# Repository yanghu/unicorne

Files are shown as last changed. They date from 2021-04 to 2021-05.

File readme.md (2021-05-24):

# Unicorne - A single-piece 40% ortho keyboard inspired by Corne and more.

This is the keyboard design files for my own use, inspired by
[crkbd](https://github.com/foostan/crkbd),
[Kyria](https://blog.splitkb.com/blog/introducing-the-kyria) and
[Ferris](https://github.com/pierrechevalier83/ferris), as well as
[Reviung41](https://github.com/gtips/reviung) and others.

The name means "uni(single-piece)corne".

## Summary of board features

* USB-C connector
* Audio buzzer
* Rotary encoder x 2 (optional)
* Underglow RGB LEDs x8
* SMT32 MCU (STM32F411)
* OLED display
* Column stagger similar to Kyria.
* Corne-style thumb cluster with extra inner key: I feel Kyria's thumb cluster 
is too much and the outer column is hard to reach for me. 
* Thumb cluster shifted 0.25u to the middle.

## Links

* [PCB repo](unicorne-mx/unicorne).
* [PCB ibom
](https://yanghu.github.io/unicorne/artifacts/ibom/unicorn-ibom.html)
* [Fabrication files and firmware](https://github.com/yanghu/unicorne/releases/tag/v1.0)
* [QMK firmware repo](https://github.com/yanghu/qmk_firmware/tree/unicorne/keyboards/yanghu/unicorne).
* [Build guide](https://github.com/yanghu/unicorne/wiki/Build-guide)

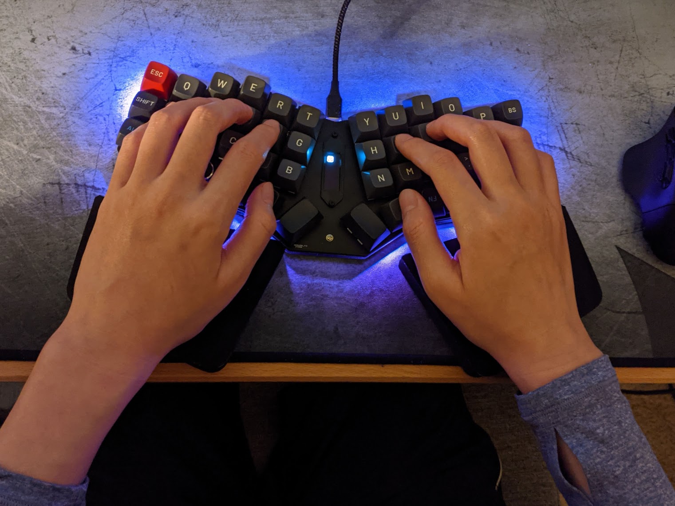
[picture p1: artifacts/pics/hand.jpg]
hand

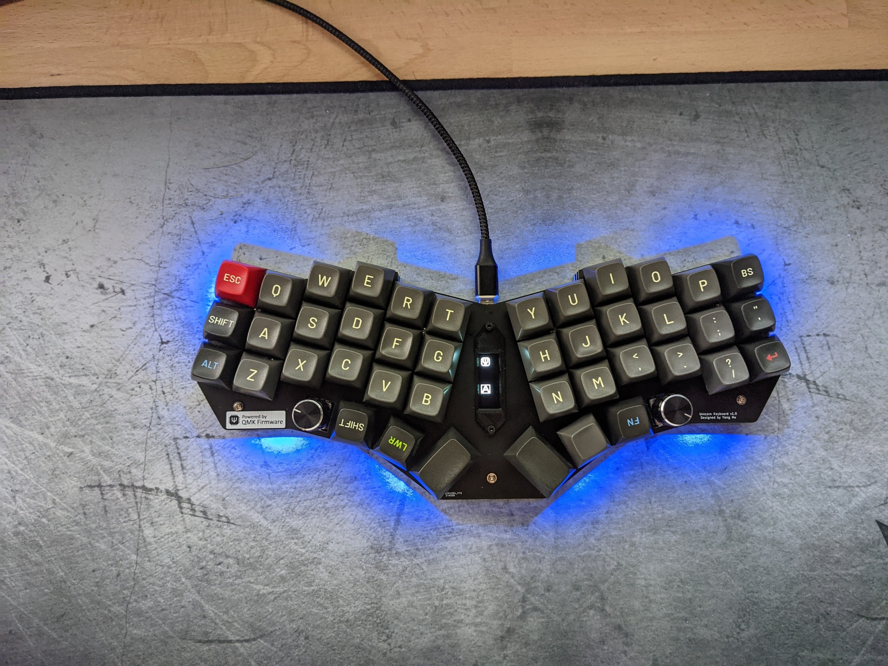
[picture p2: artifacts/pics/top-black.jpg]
keyboard

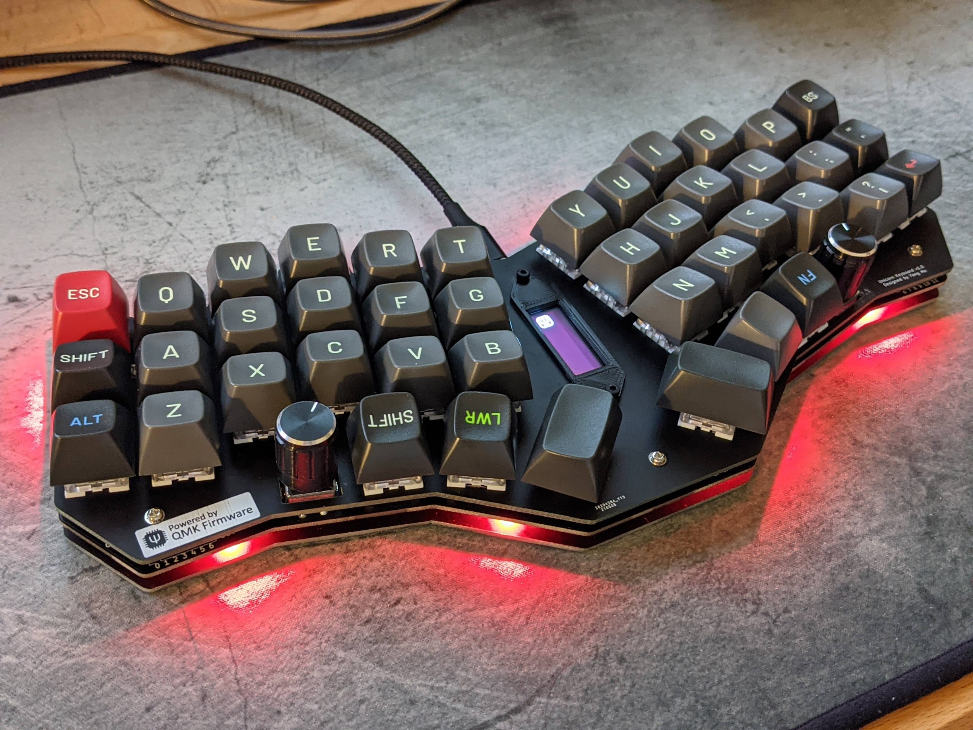
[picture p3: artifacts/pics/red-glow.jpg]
keyboard2

pcb1

## Why I designed this board

I like the simplicity of Corne, however, the more aggresive column stagger
on Kyria suits my hand better. I also removed the use of pro micro boards, and
followed Ferris 2.0 with an ARM chip directly on the board.

The initial reason I wanted to design this board is to eliminate the ugly
"add-on" board of promicro. Ferris is nice but I needed a 3x6 with full thumb
clusters as well: portability is not an issue for me.

I initially thought about building a split keyboard, however, after used crkbd
for a while, I missed the simplicity of a one-piece board: it's always symmetric
and has smaller footprint.

I do use a Planck, but *ortho* is not really a good idea on traditional keyboard
layout: the hands are so close and it's awkward to keep hands "vertical": the
wrist really is painful, especially after used to more ergonomic splits.

Reviung-like keyboards really gave me the inspiration. The angle ensures arms
and hands are in line, while you can still use the ortho layout.

Other features are nice and in different designs. I like the buzzer on Planck
that tells you when the keyboard is alive. The small OLED really is useful to
display status information for a programmable board. The encoder can be pretty
versatile.

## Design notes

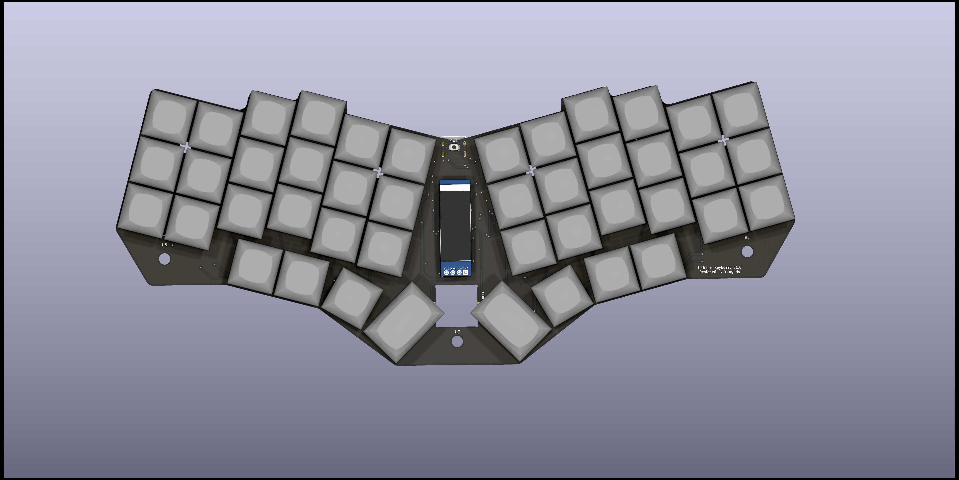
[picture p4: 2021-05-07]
artifacts/render/unicorn.png

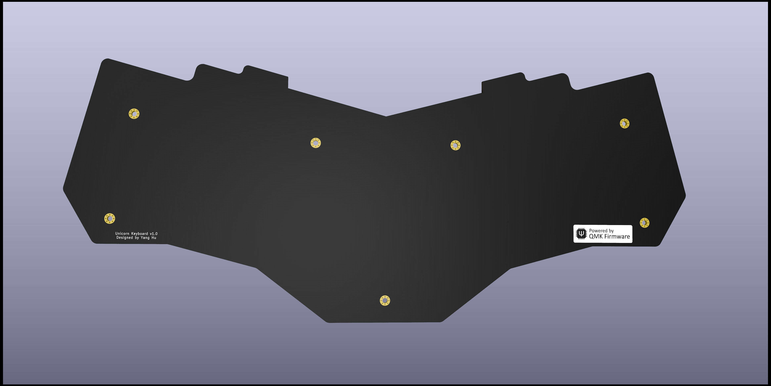
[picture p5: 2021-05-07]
artifacts/render/bottom.png

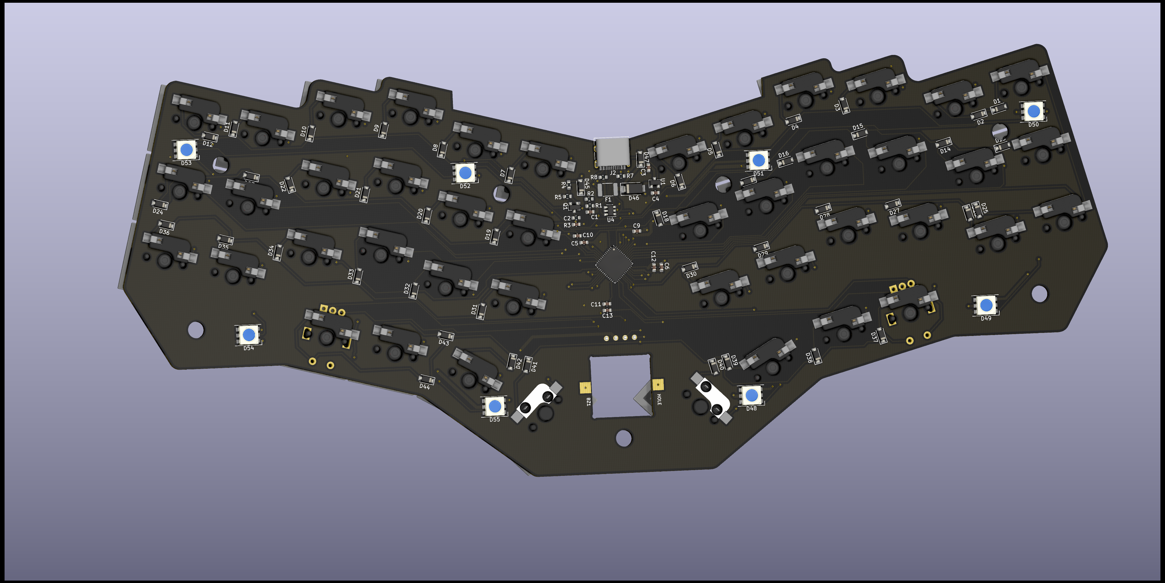
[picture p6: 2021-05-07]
artifacts/render/unicorn-back.png

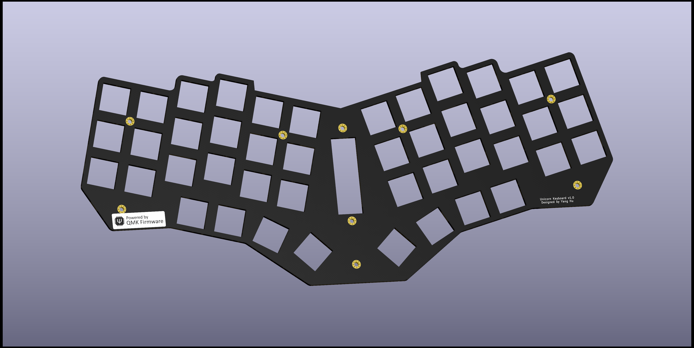
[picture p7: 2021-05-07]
artifacts/render/plate.png

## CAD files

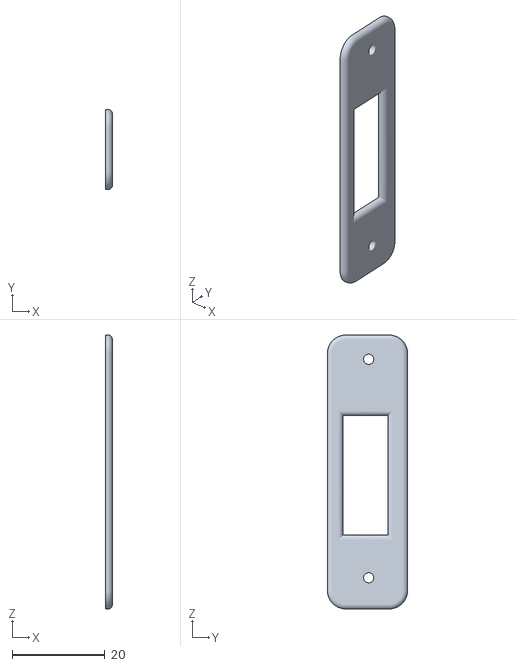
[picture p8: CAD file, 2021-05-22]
mechanical/oled-cover.stl
1.50 x 17.3 x 58.9

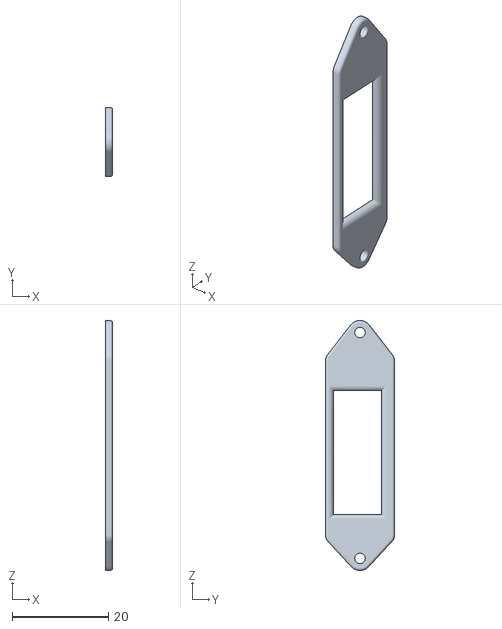
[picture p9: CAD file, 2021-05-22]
mechanical/oled-cover-v2.stl
1.50 x 14.4 x 52.0

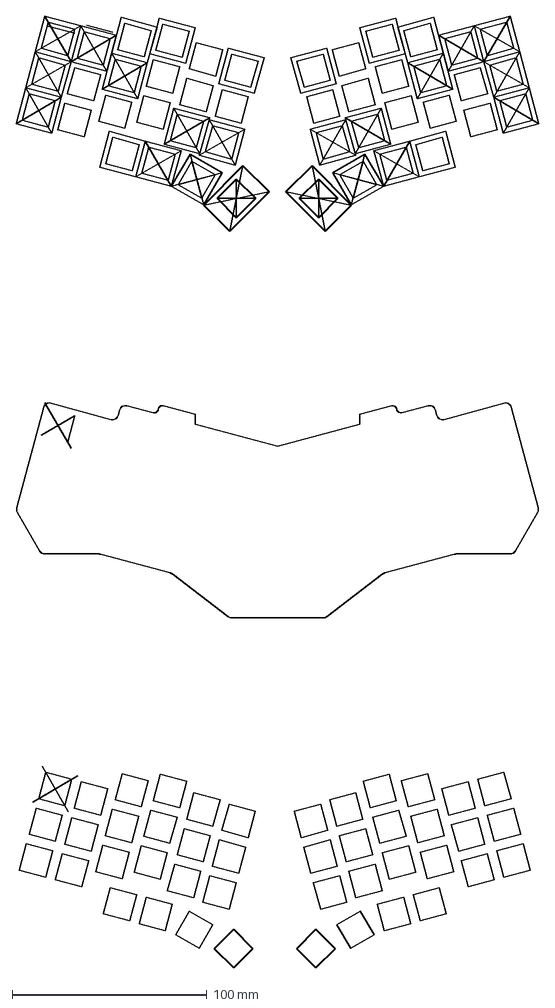
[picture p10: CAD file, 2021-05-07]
mechanical/layout.dxf
268.6 x 489.0 mm

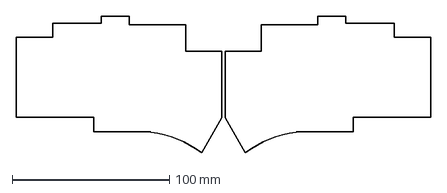
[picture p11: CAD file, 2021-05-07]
mechanical/outline.dxf
264.0 x 87.1 mm

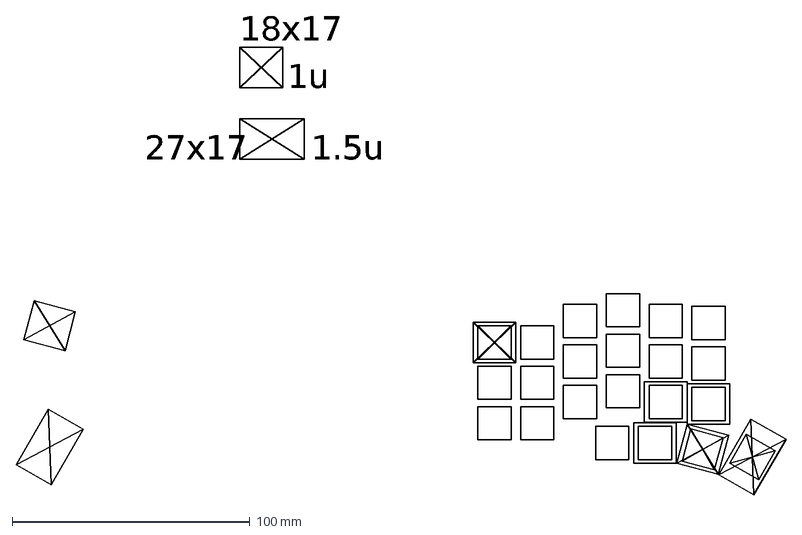
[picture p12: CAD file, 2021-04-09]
mechanical/choc-layout.dxf
1u
18x17
1.5u
27x17

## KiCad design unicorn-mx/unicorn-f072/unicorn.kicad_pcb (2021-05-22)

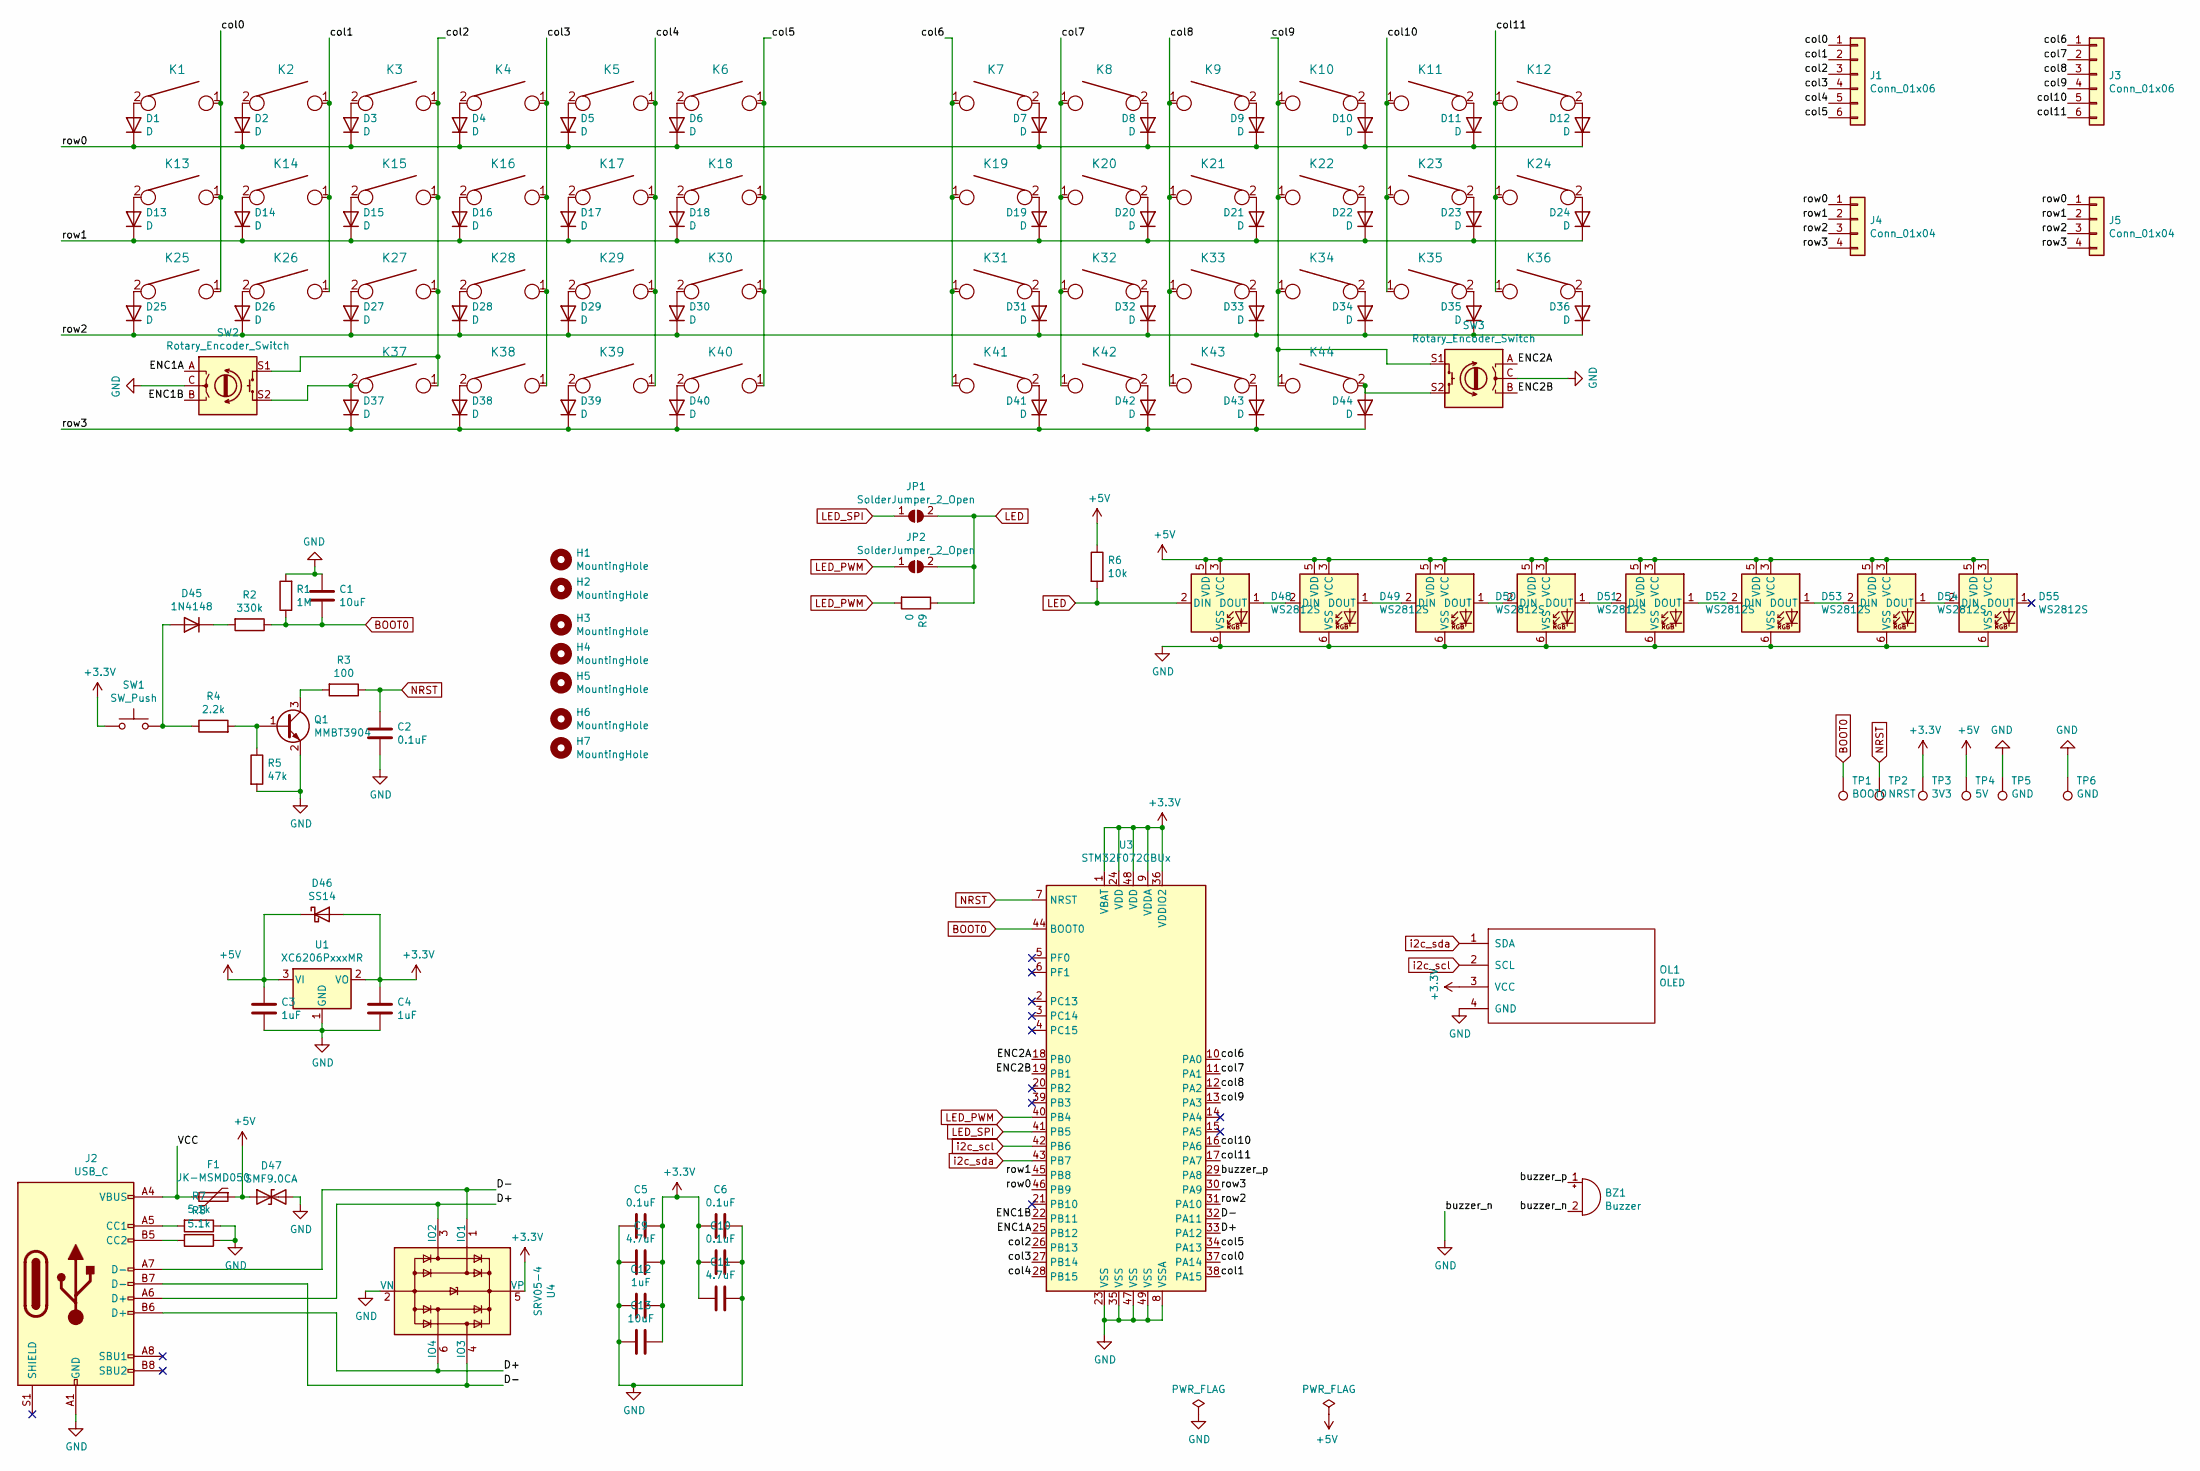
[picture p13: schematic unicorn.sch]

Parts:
BZ1: Buzzer; Piezo-KLJ-1625; LCSC Part C201041
C1, C13: 10uF; C_0603_1608Metric; LCSC Part C19702
C2, C5, C6, C10: 0.1uF; C_0603_1608Metric; LCSC Part C14663
C3, C4, C12: 1uF; C_0603_1608Metric; LCSC Part C15849
C9, C11: 4.7uF; C_0603_1608Metric; LCSC Part C19666
D1, D2, D3, D4, D5, D6, D7, D8, D9, D10, D11, D12, D13, D14, D15, D16, D17, D18, D19, D20, D21, D22, D23, D24, D25, D26, D27, D28, D29, D30, D31, D32, D33, D34, D35, D36, D37, D38, D39, D40, D41, D42, D43, D44: D; D_SOD-123; LCSC Part C81598
D45: 1N4148; D_SOD-123; LCSC Part C81598
D46: SS14; D_SMA; LCSC Part C2480
D47: SMF9.0CA; D_SOD-123; LCSC Part C435473
D48, D49, D50, D51, D52, D53, D54, D55: WS2812S; LED_WS2812_PLCC6_5.0x5.0mm_P1.6mm; LCSC Part C114584
F1: JK-MSMD050; Fuse_1812_4532Metric; LCSC Part C369167
H1, H2, H3, H4, H5, H6, H7: MountingHole; MountingHole_4.5mm
J1, J3: Conn_01x06; PinHeader_1x06_P2.54mm_Vertical
J2: USB_C; USB_C_HRO_TYPE-C-31-M-12; LCSC Part C165948
J4, J5: Conn_01x04; PinHeader_1x04_P2.54mm_Vertical
JP1, JP2: SolderJumper_2_Open; SolderJumper-2_P1.3mm_Open_TrianglePad1.0x1.5mm
K1, K2, K3, K4, K5, K6, K7, K8, K9, K10, K11, K12, K13, K14, K15, K16, K17, K18, K19, K20, K21, K22, K23, K24, K25, K26, K27, K28, K29, K30, K31, K32, K33, K34, K35, K36, K37, K38, K39, K42, K43, K44: KEYSW; CherryMX_Hotswap
K40, K41: KEYSW; CherryMX_Hotswap_1.5u
OL1: OLED; OLED_v2
Q1: MMBT3904; SOT-23; LCSC Part C20526
R1: 1M; R_0603_1608Metric; LCSC Part C22935
R2: 330k; R_0603_1608Metric; LCSC Part C23137
R3: 100; R_0603_1608Metric; LCSC Part C22775
R4: 2.2k; R_0603_1608Metric; LCSC Part C4190
R5: 47k; R_0603_1608Metric; LCSC Part C25819
R6: 10k; R_0603_1608Metric; LCSC Part C25804
R7, R8: 5.1k; R_0603_1608Metric; LCSC Part C23186
R9: 0; R_0603_1608Metric; LCSC Part C21189
SW1: SW_Push; SW_SPST_B3U-1000P; LCSC Part C231329
SW2, SW3: Rotary_Encoder_Switch; RotaryEncoder_EC11
TP1: BOOT0; TestPoint_THTPad_D1.5mm_Drill0.7mm
TP2: NRST; TestPoint_THTPad_D1.5mm_Drill0.7mm
TP3: 3V3; TestPoint_THTPad_D1.5mm_Drill0.7mm
TP4: 5V; TestPoint_THTPad_D1.5mm_Drill0.7mm
TP5, TP6: GND; TestPoint_THTPad_D1.5mm_Drill0.7mm
U1: XC6206PxxxMR; SOT-23; LCSC Part C5446
U3: STM32F072CBUx; QFN-48-1EP_7x7mm_P0.5mm_EP5.15x5.15mm_ThermalVias; LCSC Part C92504
U4: SRV05-4; SOT-23-6; LCSC Part C85364

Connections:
+3V3: C4.2, C5.1, C6.2, C9.1, C10.2, C11.2, C12.1, C13.1, D46.2 (A), OL1.3 (VCC), SW1.1, TP3.1, U1.2 (VO), U3.1 (VBAT), U3.9 (VDDA), U3.24 (VDD), U3.36 (VDDIO2), U3.48 (VDD), U4.5 (VP)
+5V: C3.2, D46.1 (K), D47.1 (A1), D48.3 (VCC), D48.5 (VDD), D49.3 (VCC), D49.5 (VDD), D50.3 (VCC), D50.5 (VDD), D51.3 (VCC), D51.5 (VDD), D52.3 (VCC), D52.5 (VDD), D53.3 (VCC), D53.5 (VDD), D54.3 (VCC), D54.5 (VDD), D55.3 (VCC), D55.5 (VDD), F1.1, R6.1, TP4.1, U1.3 (VI)
/D+: J2.A6 (D+), J2.B6 (D+), U3.33 (PA12), U4.3 (IO2), U4.6 (IO4)
/D-: J2.A7 (D-), J2.B7 (D-), U3.32 (PA11), U4.1 (IO1), U4.4 (IO3)
/ENC1A: SW2.A, U3.25 (PB12)
/ENC1B: SW2.B, U3.22 (PB11)
/ENC2A: SW3.A, U3.18 (PB0)
/ENC2B: SW3.B, U3.19 (PB1)
/VCC: F1.2, J2.A4 (VBUS), J2.A9 (VBUS), J2.B4 (VBUS), J2.B9 (VBUS)
/buzzer_p: BZ1.1 (-), U3.29 (PA8)
/col0: J1.1, K1.1, K13.1, K25.1, U3.37 (PA14)
/col1: J1.2, K2.1, K14.1, K26.1, U3.38 (PA15)
/col2: J1.3, K3.1, K15.1, K27.1, K37.1, SW2.S1, U3.26 (PB13)
/col3: J1.4, K4.1, K16.1, K28.1, K38.1, U3.27 (PB14)
/col4: J1.5, K5.1, K17.1, K29.1, K39.1, U3.28 (PB15)
/col5: J1.6, K6.1, K18.1, K30.1, K40.1, U3.34 (PA13)
/col6: J3.1, K7.1, K19.1, K31.1, K41.1, U3.10 (PA0)
/col7: J3.2, K8.1, K20.1, K32.1, K42.1, U3.11 (PA1)
/col8: J3.3, K9.1, K21.1, K33.1, K43.1, U3.12 (PA2)
/col9: J3.4, K10.1, K22.1, K34.1, K44.1, SW3.S1, U3.13 (PA3)
/col10: J3.5, K11.1, K23.1, K35.1, U3.16 (PA6)
/col11: J3.6, K12.1, K24.1, K36.1, U3.17 (PA7)
/row0: D1.1 (K), D2.1 (K), D3.1 (K), D4.1 (K), D5.1 (K), D6.1 (K), D7.1 (K), D8.1 (K), D9.1 (K), D10.1 (K), D11.1 (K), D12.1 (K), J4.1, J5.1, U3.46 (PB9)
/row1: D13.1 (K), D14.1 (K), D15.1 (K), D16.1 (K), D17.1 (K), D18.1 (K), D19.1 (K), D20.1 (K), D21.1 (K), D22.1 (K), D23.1 (K), D24.1 (K), J4.2, J5.2, U3.45 (PB8)
/row2: D25.1 (K), D26.1 (K), D27.1 (K), D28.1 (K), D29.1 (K), D30.1 (K), D31.1 (K), D32.1 (K), D33.1 (K), D34.1 (K), D35.1 (K), D36.1 (K), J4.3, J5.3, U3.31 (PA10)
/row3: D37.1 (K), D38.1 (K), D39.1 (K), D40.1 (K), D41.1 (K), D42.1 (K), D43.1 (K), D44.1 (K), J4.4, J5.4, U3.30 (PA9)
BOOT0: C1.1, R1.1, R2.1, TP1.1, U3.44 (BOOT0)
GND: BZ1.2 (+), C1.2, C2.1, C3.1, C4.1, C5.2, C6.1, C9.2, C10.1, C11.1, C12.2, C13.2, D47.2 (A2), D48.6 (VSS), D49.6 (VSS), D50.6 (VSS), D51.6 (VSS), D52.6 (VSS), D53.6 (VSS), D54.6 (VSS), D55.6 (VSS), J2.A1 (GND), J2.A12 (GND), J2.B1 (GND), J2.B12 (GND), OL1.4 (GND), Q1.2 (E), R1.2, R5.2, R7.1, R8.1, SW2.C, SW3.C, TP5.1, TP6.1, U1.1 (GND), U3.8 (VSSA), U3.23 (VSS), U3.35 (VSS), U3.47 (VSS), U3.49 (VSS), U4.2 (VN)
LED: D48.2 (DIN), JP1.2 (B), JP2.2 (B), R6.2, R9.1
LED_PWM: JP2.1 (A), R9.2, U3.40 (PB4)
LED_SPI: JP1.1 (A), U3.41 (PB5)
NRST: C2.2, R3.1, TP2.1, U3.7 (NRST)
unnamed: D1.2 (A), K1.2
unnamed: D2.2 (A), K2.2
unnamed: D3.2 (A), K3.2
unnamed: D4.2 (A), K4.2
unnamed: D5.2 (A), K5.2
unnamed: D6.2 (A), K6.2
unnamed: D7.2 (A), K7.2
unnamed: D8.2 (A), K8.2
unnamed: D9.2 (A), K9.2
unnamed: D10.2 (A), K10.2
unnamed: D11.2 (A), K11.2
unnamed: D12.2 (A), K12.2
unnamed: D13.2 (A), K13.2
unnamed: D14.2 (A), K14.2
unnamed: D15.2 (A), K15.2
unnamed: D16.2 (A), K16.2
unnamed: D17.2 (A), K17.2
unnamed: D18.2 (A), K18.2
unnamed: D19.2 (A), K19.2
unnamed: D20.2 (A), K20.2
unnamed: D21.2 (A), K21.2
unnamed: D22.2 (A), K22.2
unnamed: D23.2 (A), K23.2
unnamed: D24.2 (A), K24.2
unnamed: D25.2 (A), K25.2
unnamed: D26.2 (A), K26.2
unnamed: D27.2 (A), K27.2
unnamed: D28.2 (A), K28.2
unnamed: D29.2 (A), K29.2
unnamed: D30.2 (A), K30.2
unnamed: D31.2 (A), K31.2
unnamed: D32.2 (A), K32.2
unnamed: D33.2 (A), K33.2
unnamed: D34.2 (A), K34.2
unnamed: D35.2 (A), K35.2
unnamed: D36.2 (A), K36.2
unnamed: D37.2 (A), K37.2, SW2.S2
unnamed: D38.2 (A), K38.2
unnamed: D39.2 (A), K39.2
unnamed: D40.2 (A), K40.2
unnamed: D41.2 (A), K41.2
unnamed: D42.2 (A), K42.2
unnamed: D43.2 (A), K43.2
unnamed: D44.2 (A), K44.2, SW3.S2
unnamed: D45.1 (K), R2.2
unnamed: D45.2 (A), R4.1, SW1.2
unnamed: D48.1 (DOUT), D49.2 (DIN)
unnamed: D49.1 (DOUT), D50.2 (DIN)
unnamed: D50.1 (DOUT), D51.2 (DIN)
unnamed: D51.1 (DOUT), D52.2 (DIN)
unnamed: D52.1 (DOUT), D53.2 (DIN)
unnamed: D53.1 (DOUT), D54.2 (DIN)
unnamed: D54.1 (DOUT), D55.2 (DIN)
unnamed: J2.A5 (CC1), R7.2
unnamed: J2.B5 (CC2), R8.2
unnamed: Q1.1 (B), R4.2, R5.1
unnamed: Q1.3 (C), R3.2
i2c_scl: OL1.2 (SCL), U3.42 (PB6)
i2c_sda: OL1.1 (SDA), U3.43 (PB7)

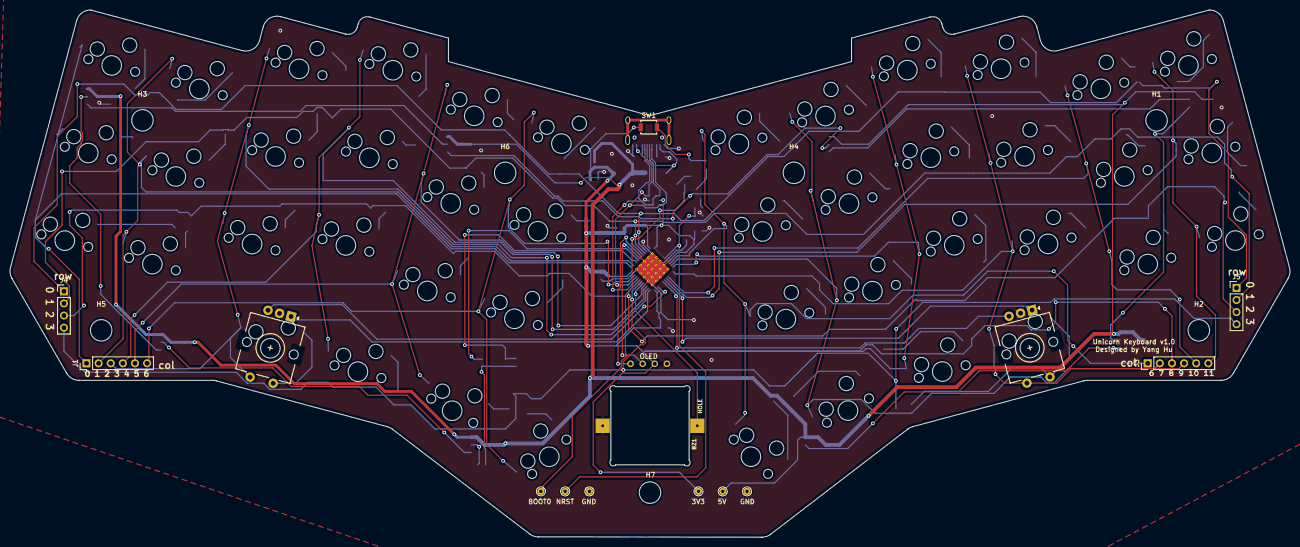
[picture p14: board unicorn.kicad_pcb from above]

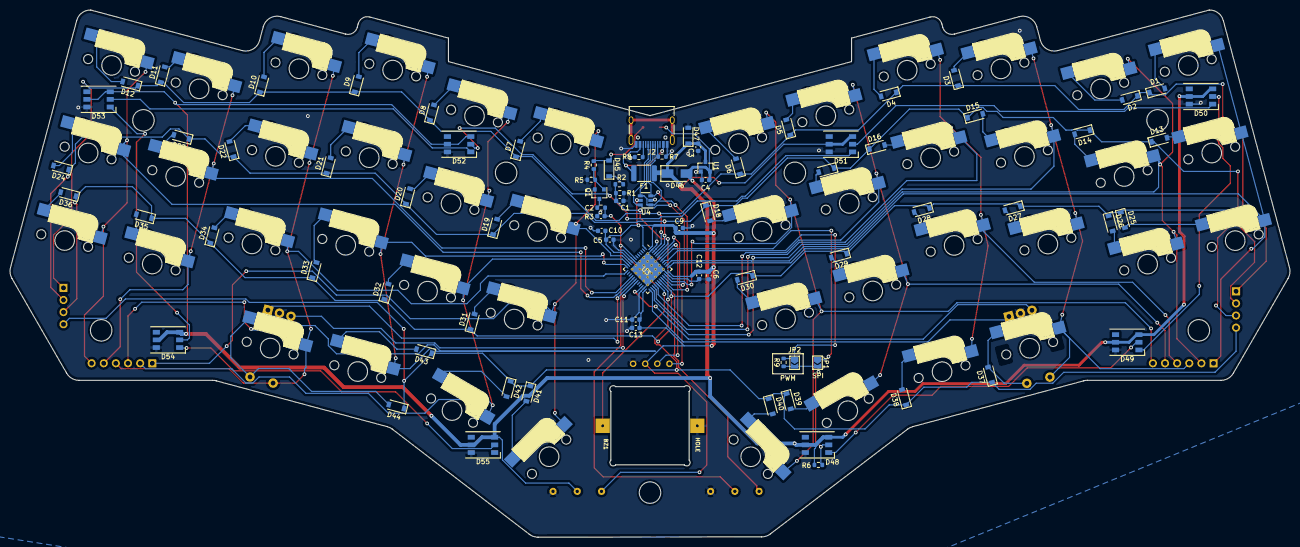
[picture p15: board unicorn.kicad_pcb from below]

Board: 2 copper layers, 268.2 x 110.5 mm, 149 parts (83 on the bottom side), 91 nets.

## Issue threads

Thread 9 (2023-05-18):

problem if compile layout in recent QMK

jjibagar, 2023-05-18:
I have compiled with the most recent version of QMK as of May 2023 the default layout of the yanghu/unicorne (STM32F411) and when flashing it leaves the keyboard inactive until it is flashed again with a valid bin, made with my old QMK that It's 0.16.8.
Has anyone had this happen or know why this happens?

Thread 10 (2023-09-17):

accidentally deleted the adjust layer and flashed the board, can't reset to bootloader mode anymore

sumtsui, 2023-09-17:
any other way to enter bootloader mode?

Closed 2023-09-17.

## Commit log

2021-04-09 add keyboard layout dxf and ble board
    [choc-layout.dxf, layout.dxf]
2021-04-09 add symbol and footprint libs
2021-04-09 initial drawing: draw switch array
    [korris.kicad_pcb, korris.sch]
2021-04-17 layout switches
    [choc-layout.dxf, korris.kicad_pcb, korris.sch]
2021-04-18 add outline for choc layout
    [choc-layout.dxf, korris.kicad_pcb, korris.sch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]
2021-04-19 routed left half
    [korris.kicad_pcb, korris.sch]
2021-04-25 add unicorn design
    [choc-layout.dxf, korris.kicad_pcb, layout.dxf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]
2021-04-25 add 3d models, add oled
    [unicorn.kicad_pcb, unicorn.sch]
2021-04-26 finalize unicorn design
    [layout.dxf, unicorn.kicad_pcb, unicorn.sch]
2021-04-30 add plate and bottom, add rendered images
    [bottom.kicad_pcb, bottom.sch, layout.dxf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]
2021-05-07 Add automation files: now use `make unicorn` or `make unicorn-doc` to generate output and `make clean` to clean up
    [unicorn.kicad_pcb, unicorn.sch]
2021-05-07 route pcb with new pin assginments, add bridges for led, add test points
    [unicorn.kicad_pcb, unicorn.sch]
2021-05-08 use f411 mcu
    [unicorn.kicad_pcb, unicorn.sch]
2021-05-08 fix jlcpcb smt position automation: no need to do extra rotation
    [unicorn.sch]
2021-05-08 Add back rotation for jlcpcb positions, as most footproints still needs rotation.
    [unicorn.kicad_pcb, unicorn.sch]
2021-05-08 add f072 variant design
    [unicorn.kicad_pcb, unicorn.sch]
2021-05-22 add artifacts folder
    [oled-cover-v2.stl, oled-cover.stl]
